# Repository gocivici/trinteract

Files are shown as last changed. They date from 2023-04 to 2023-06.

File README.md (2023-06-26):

# Trinteract





This repository contains all the files and documentation for Trinteract, An open-source Arduino-compatible 3DOF Human Interface Device (HID). In other words a joystick that's capable of moving in all 3 Dimensions. Trinteract uses a 3D magnetometer and a Neodymium magnet to detect motion in 3D space.  [Visit the DIY guide](https://www.instructables.com/Trinteract-an-Open-source-3D-Input-Device/)

[Watch the Demo here](https://youtu.be/YoGgdORVARs)

File structure:
+  `Software` contains the arduino code and necessary drivers 
+  `PCB` contains the KiCAD PCB files and gerber files for manufacturing
+  `docs` contains the source code for the documentation website build with [Sphinx](https://www.sphinx-doc.org/en/master/index.html)
+  `CAD` contains all fusion360 CAD files and print ready .stl files  

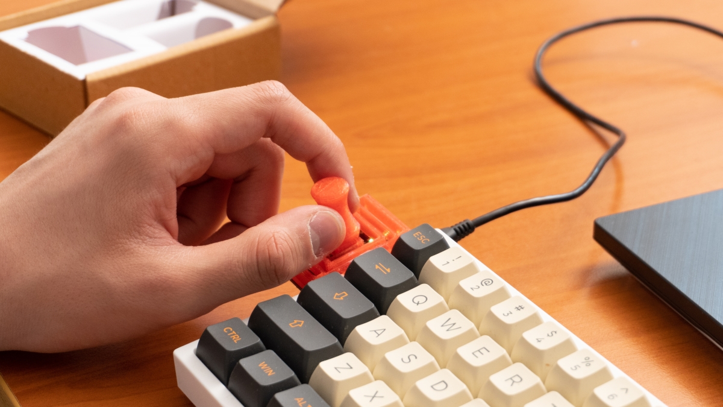
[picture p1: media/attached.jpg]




Before Assembly            |  Assembled
:-------------------------:|:-------------------------:
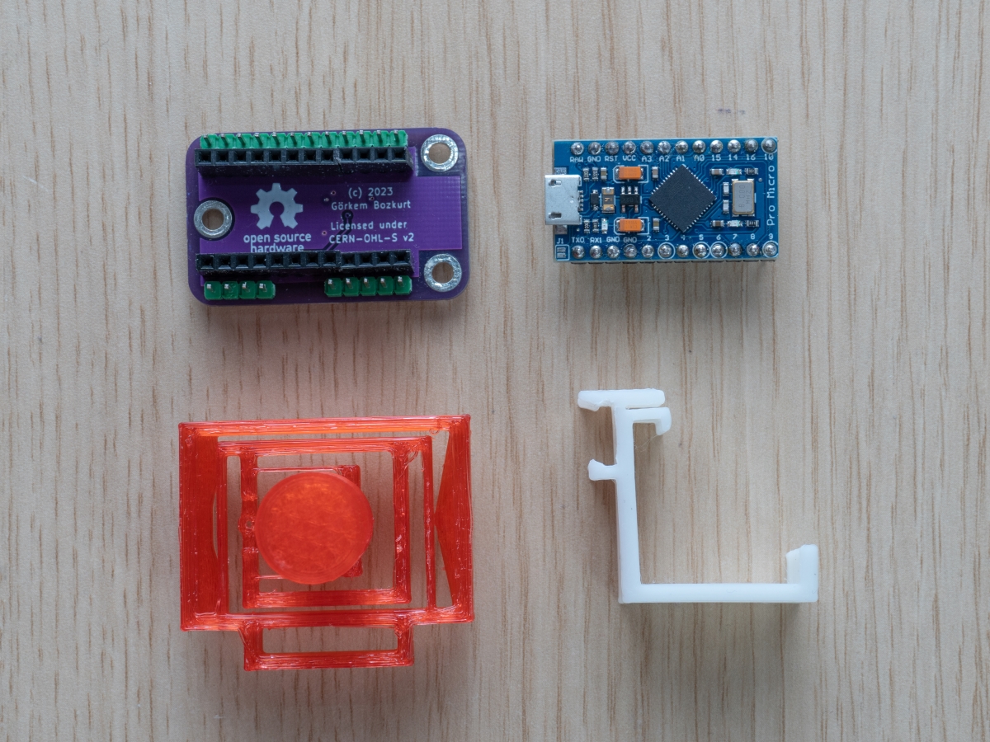
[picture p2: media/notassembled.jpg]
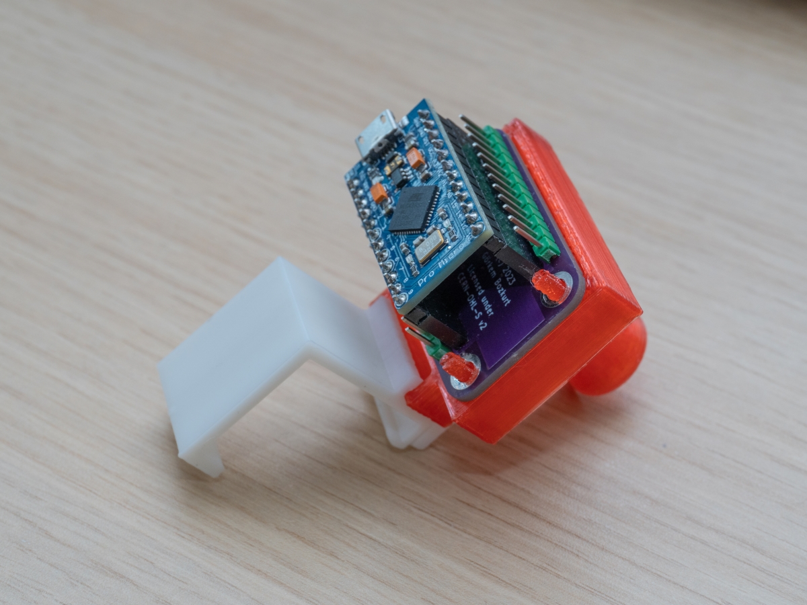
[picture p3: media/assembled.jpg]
  |  

<p align="center" width="100%">
    
</p>
<p align="center" width="100%">
<a href="https://certification.oshwa.org/ee000001.html">[OSHW] EE00001 | Certified open source hardware</a>
</p>

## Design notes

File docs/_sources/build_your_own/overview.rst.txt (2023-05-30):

Overview
========

Trinteract is basically a compact breakout board for the TLV493 Magnetometer. You can use off-the-shelf components to prototype it first before you 
order a PCB. Here's a wiring guide for a simple prototype that features the magnetic sensor, an Arduino pro micro, a LED and a tactile button: 

.. image:: wiring.png

If you decide to manufacture the PCB you can follow `this interactive BOM guide <../ibom.html>`_ to keep track of the parts: 

Parts for PCB
-------------

* :doc:`Trinteract pcb </build_your_own/Fabrication>` 
* `Infenion TLV493DA Low Power 3D Magnetic Sensor <https://eu.mouser.com/ProductDetail/Infineon-Technologies/TLV493DA1B6HTSA2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>`_
* '2 x 2.2k Ω SMD Resistor 0805 - R1 & R3
* '680 Ω SMD Resistor 0805 - R2
* '4.7k Ω SMD Resistor 0805 - R4
* '100n SMD Capacitor 0805 - C1
* 'Tactile Switch 5 X 5mm,  2 mm Actuator Height
* 4x4mm neodymium cube magnet

': *These parts can be bought from any major electronics supplier, like Digikey or Mouser*

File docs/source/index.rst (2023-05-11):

Contents
--------
.. toctree::
   :maxdepth: 2
   :caption: ✨ Getting Started

   getting_started/Quick Start
   getting_started/Installation
   getting_started/Configuration
   getting_started/Examples

.. toctree::
   :maxdepth: 2
   :caption: 🛠️ Build Your Own

   build_your_own/overview
   build_your_own/Fabrication
   build_your_own/Soldering
   build_your_own/3D Printing
   build_your_own/Testing
.. toctree::
   :maxdepth: 2
   :caption: 📖 Development

   development/About
   development/Contributing
   development/Changelog

Indices and tables
==================

* :ref:`genindex`
* :ref:`modindex`
* :ref:`search`

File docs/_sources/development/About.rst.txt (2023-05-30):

About
=====

About Trinteract
----------------

Trinteract was developed as part of an Interaction design Masters thesis project in May 2023, the starting point for the project was the challanges of navigating 3D environments and 
the absence of universal  3D  input  devices for the average user. 

It combines the advantages of the mouse and existing commercial devices like the SpaceMouse to provide an easy-to-learn customizable 3DOF navigation experience.

About this documentation
------------------------

This documentation was build in parallel with the development of trinteract and aims to encougrage user involvement through the development process. 

If you want to contribute to Trinteract or this document, please see: :doc:`Contributing <Contributing>`

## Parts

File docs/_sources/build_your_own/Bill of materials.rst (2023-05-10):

Bill of materials(BOM)
======================

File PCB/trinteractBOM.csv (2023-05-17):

Id | Designator | Package | Quantity | Designation | Supplier and ref
1 | D1 | 156120GS82500 | 1 | LED
2 | R3,R1 | R_0805_2012Metric_Pad1.20x1.40mm_HandSolder | 2 | 2k2
3 | R2 | R_0805_2012Metric_Pad1.20x1.40mm_HandSolder | 1 | 680R
4 | U1 | TLV493DA1B6HTSA2 | 1 | TLV493DA1B6HTSA2
5 | C1 | C_0805_2012Metric_Pad1.18x1.45mm_HandSolder | 1 | 100n
6 | U2 | ARDUINO_PRO_MICRO | 1 | ProMicro
7 | SW1 | SW_SPST_TL3342 | 1 | SW_Push
8 | J3 | Female_Header_1x12-Pin_P2.54mm_Horizontal | 2 | 1x12
9 | R4 | R_0805_2012Metric_Pad1.20x1.40mm_HandSolder | 1 | 4k7

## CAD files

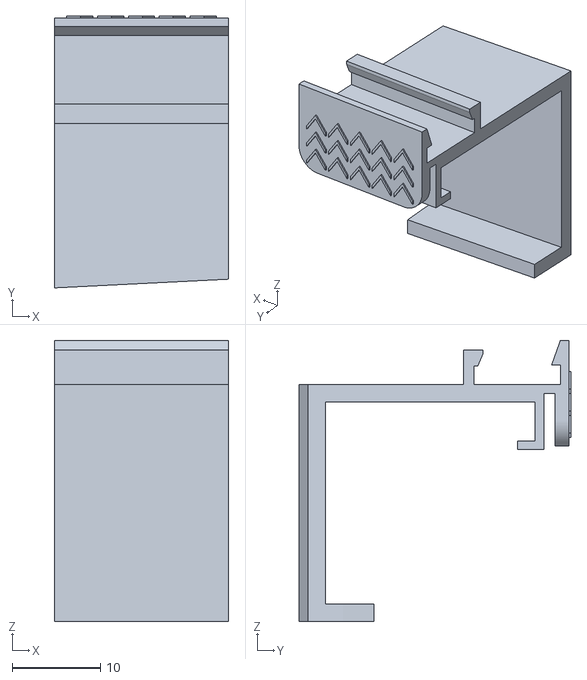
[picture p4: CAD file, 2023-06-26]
CAD/stl/KeyboardAdapter.stl
19.8 x 30.8 x 31.9

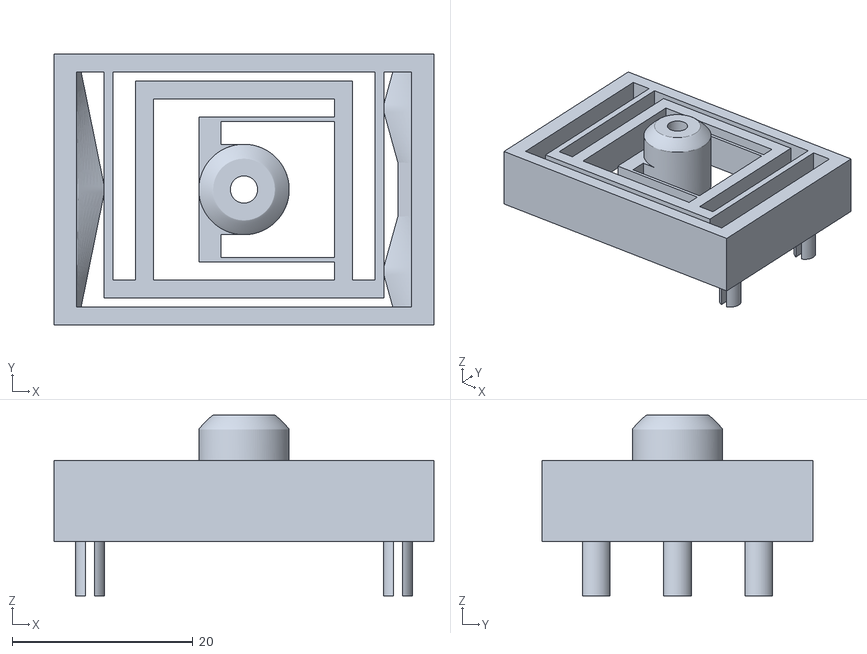
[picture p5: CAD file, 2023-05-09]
CAD/stl/base.stl
42.0 x 30.0 x 20.0

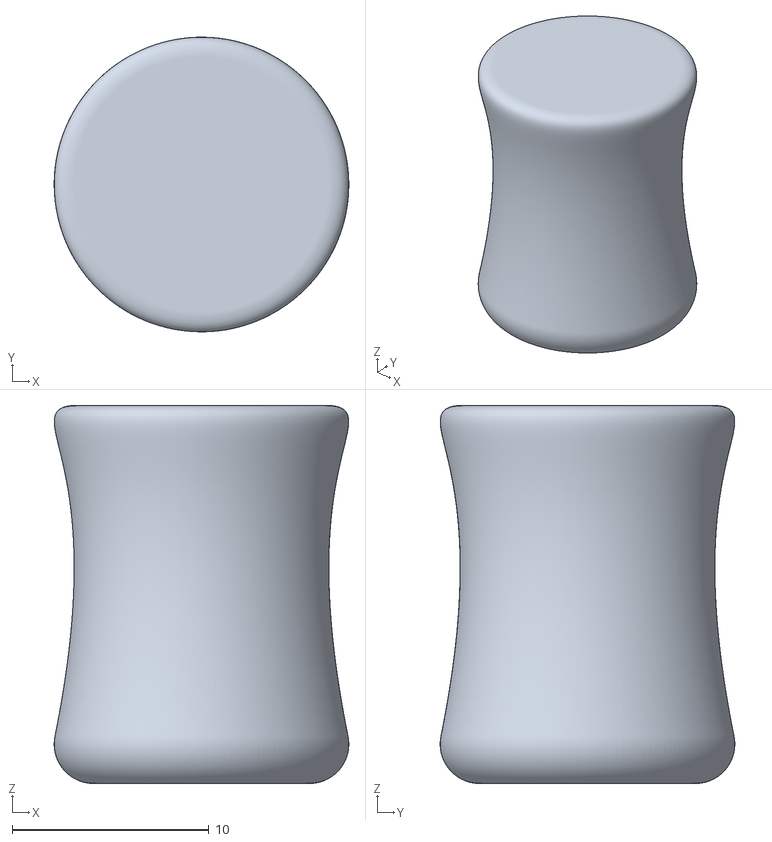
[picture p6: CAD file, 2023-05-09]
CAD/stl/knob.stl
15.0 x 15.0 x 19.2

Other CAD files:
CAD/KeyboardAdapter.f3z
CAD/base.f3d
CAD/knob.f3d

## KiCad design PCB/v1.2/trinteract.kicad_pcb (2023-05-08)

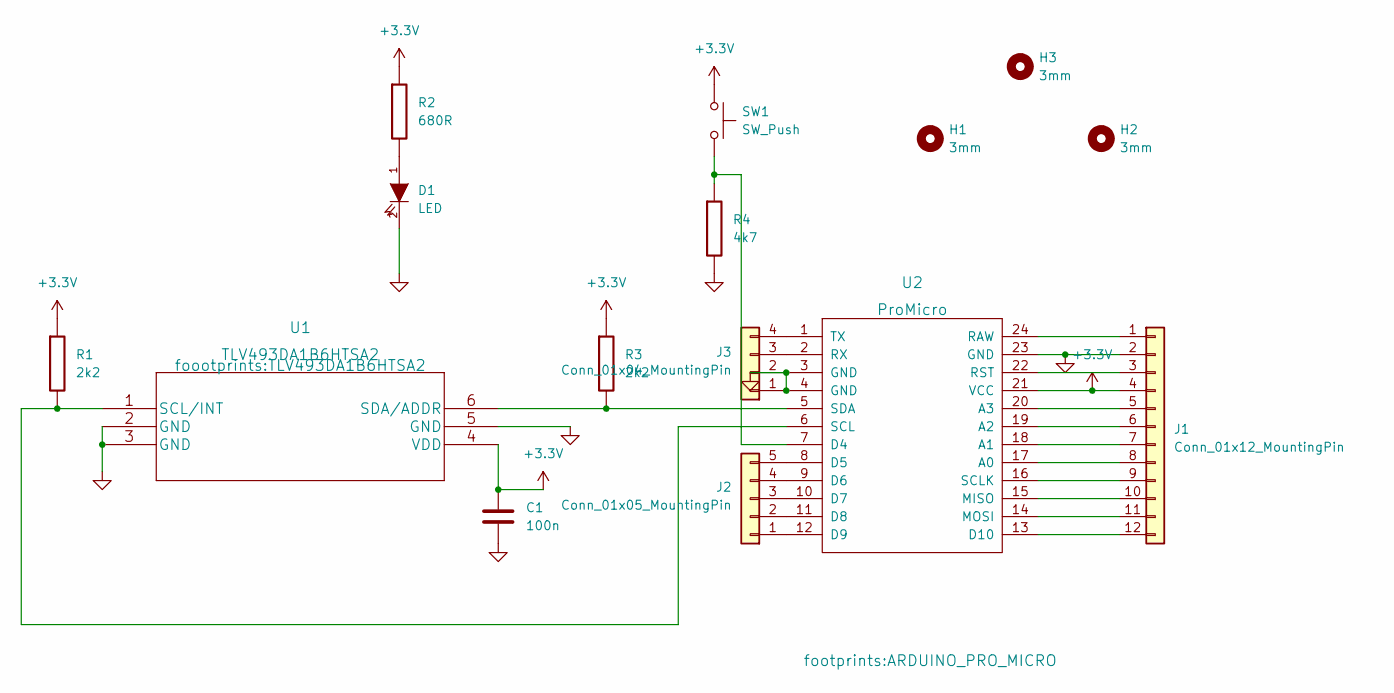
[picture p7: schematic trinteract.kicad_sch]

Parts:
C1: 100n; C_0805_2012Metric_Pad1.18x1.45mm_HandSolder
D1: LED; 156120GS82500
H1, H2, H3: 3mm; MountingHole_3.2mm_M3_DIN965_Pad
J1: Conn_01x12_MountingPin; PinHeader_1x12_P2.54mm_Horizontal
J2: Conn_01x05_MountingPin; PinHeader_1x05_P2.54mm_Horizontal
J3: Conn_01x04_MountingPin; PinHeader_1x04_P2.54mm_Horizontal
R1, R3: 2k2; R_0805_2012Metric_Pad1.20x1.40mm_HandSolder
R2: 680R; R_0805_2012Metric_Pad1.20x1.40mm_HandSolder
R4: 4k7; R_0805_2012Metric_Pad1.20x1.40mm_HandSolder
SW1: SW_Push; SW_SPST_TL3342
U1: TLV493DA1B6HTSA2
U2: ProMicro; ARDUINO_PRO_MICRO

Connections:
+3.3V: C1.1, J1.4, R1.1, R2.1, R3.1, SW1.1, U1.4 (VDD), U2.21 (VCC)
GND: C1.2, D1.2 (K), J1.2, J3.1, J3.2, R4.2, U1.2 (GND), U1.3 (GND), U1.5 (GND), U2.3 (GND), U2.4 (GND), U2.23 (GND)
unnamed: D1.1 (A), R2.2
unnamed: R1.2, U1.1 (SCL/INT), U2.6 (SCL)
unnamed: R3.2, U1.6 (SDA/ADDR), U2.5 (SDA)
unnamed: R4.1, SW1.2, U2.7 (D4)
unnamed: J3.4, U2.1 (TX)
unnamed: J3.3, U2.2 (RX)
unnamed: J2.5, U2.8 (D5)
unnamed: J2.4, U2.9 (D6)
unnamed: J2.3, U2.10 (D7)
unnamed: J2.2, U2.11 (D8)
unnamed: J2.1, U2.12 (D9)
unnamed: J1.12, U2.13 (D10)
unnamed: J1.11, U2.14 (MOSI)
unnamed: J1.10, U2.15 (MISO)
unnamed: J1.9, U2.16 (SCLK)
unnamed: J1.8, U2.17 (A0)
unnamed: J1.7, U2.18 (A1)
unnamed: J1.6, U2.19 (A2)
unnamed: J1.5, U2.20 (A3)
unnamed: J1.3, U2.22 (RST)
unnamed: J1.1, U2.24 (RAW)

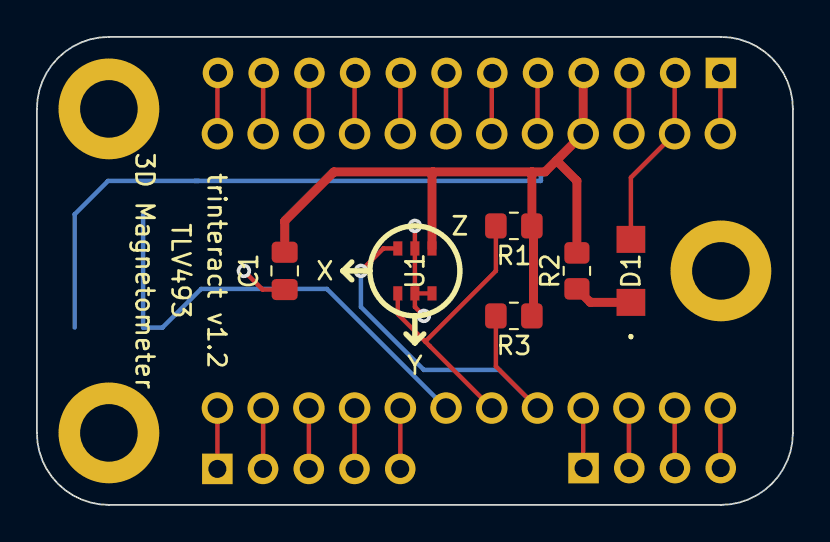
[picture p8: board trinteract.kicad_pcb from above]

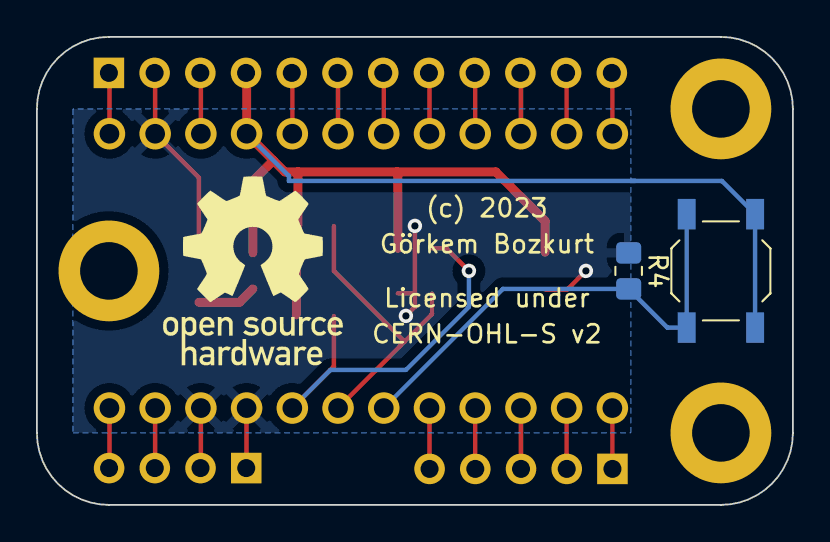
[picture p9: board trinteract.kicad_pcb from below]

Board: 2 copper layers, 42.0 x 26.0 mm, 15 parts (5 on the bottom side), 23 nets.

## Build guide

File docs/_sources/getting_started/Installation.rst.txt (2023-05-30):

Interactive Tutorial
====================
This interactive guide will guide you through the capabilities of the sensor. But first you have to use a plugin to let figma communicate with trinteract.

Launch Figma and go to ``Plugins`` and search for "3DConnexion SpaceMouse Driver" by Chuanqi Sun

Attach Trinteract to your computer and you are ready to navigate Figma! 

.. raw:: html

    <iframe style="border: 1px solid rgba(0, 0, 0, 0.1);" width="800" height="450" src="https://www.figma.com/embed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" allowfullscreen></iframe>

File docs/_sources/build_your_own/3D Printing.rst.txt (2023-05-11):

3D Printing
===========

.. image:: cura.png
    :width: 80%
    :align: center

The latest CAD files can downloaded from `this link. <https://github.com/gocivici/trinteract/archive/refs/heads/master.zip>`_ The CAD files can be edited in Fusion360. You can also use the .stl files directly for the 3D printing.

The 3D prints were done on a fdm printer with a eSun PLA+ filament. The following settings were used for the print:

* Layer Height: 0.25mm
* Wall thickness: 1.2mm
* infill: 50%
* Generate support, Overhang Angle:60

.. image:: 3D.jpg
    :width: 45%

.. image:: 3D2.jpg
    :width: 45%

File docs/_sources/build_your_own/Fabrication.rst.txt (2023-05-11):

PCB Fabrication
===============

Schematic and PCB
-----------------

.. image:: pcb.png

The latest PCB files can downloaded from `this link <https://github.com/gocivici/trinteract/archive/refs/heads/master.zip>`_

There are two subfolders under the PCB folder. One contains the KiCAD files that can be edited and customized. The other folder titled "Gerbers" contains the manufacture ready files 
that can be directly sent to a PCB manufacturer like JLCPCB.

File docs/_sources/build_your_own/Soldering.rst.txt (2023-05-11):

Soldering
=========

SMD Components
--------------

.. image:: solder.jpg
    :width: 45%

.. image:: solder2.jpg
    :width: 45%

.. note::
   The PCB in these pictures are from the previous version, I'll update them once I receive the new batch. The only difference in the new version is the button placement. The newer version has the button on the back.

The components can be soldered on to the PCB by hand, but you could also use solder paste and a reflow oven to make the process easier. I followed this tutorial 
for the hand soldering:

.. raw:: html
    
    <iframe width="560" height="315" src="https://www.youtube.com/embed/4zXP0TtORWo" title="YouTube video player" frameborder="0" allow="accelerometer; autoplay; clipboard-write; encrypted-media; gyroscope; picture-in-picture; web-share" allowfullscreen></iframe>

Through-Hole Components
-----------------------

The only Through-Hole components in this build are te header pins. You can also solder additional expansion pins if you plan to prototype with the board.

.. image:: hole.jpg
    :width: 60%
    :align: center

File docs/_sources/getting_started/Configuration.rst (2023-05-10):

Configuration
=============

The Arduino code for trinteract can be found in the Software folder in the github repository. You can download the latest version by clicking the following link: https://github.com/gocivici/trinteract/archive/refs/heads/master.zip

Different Magnet
----------------

the Arduino code comes configured and calibrated based on a 4x4mm neodymium magnet. If you want to use a different magnet or magnetic material like magnetic textiles etc. you have to
configure the range of the magnetic field in the Arduino code.

First uncomment the following lines to open the serial port:

.. code-block:: c++

  //  uncomment the following line for debugging
  Serial.begin(9600);

.. code-block:: c++

  Serial.print(Tlv493dMagnetic3DSensor.getX());
  Serial.print(Tlv493dMagnetic3DSensor.getY());
  Serial.println(Tlv493dMagnetic3DSensor.getZ());

Next, upload the code to arduino and launch the serial monitor to see the new values. Now move the magnet to the maximum and minimum ends to determine the range of values.

Replace ``xMin``, ``xMax``, ``yMin``, ``yMax``, ``zMin``, ``zMax`` with the new values.

.. code-block:: c++

  int y = map((calX-Tlv493dMagnetic3DSensor.getX()),yMax,yMin,-64,64);
  int x = map((calY-Tlv493dMagnetic3DSensor.getY()),xMax,xMin,-64,64);
  int z = map((calZ-Tlv493dMagnetic3DSensor.getZ()),zMin,zMax,-64,64);

The Button
----------

The button on trinteract is set up as a calibration button, however calibration is also implemented on boot so you can configure to use it to control something else. If you decide to do so you can 
comment the following line in the arduino code:

.. code-block:: c++

    // comment the following lines if you want to use the button for something else
    if(digitalRead(calButton) || !calibrationState){
      calibrate();
      calibrationState = true;
    }

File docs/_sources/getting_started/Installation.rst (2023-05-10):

Interactive Tutorial
====================
This interactive guide will guide you throug the capabilities of the sensor. But first you have to use a plugin to let figma communicate with trinteract.
download the zxyKit driver from here, unzip the folder and on Figma goto Plugins → Development → trinteract Driver.

.. raw:: html

    <iframe style="border: 1px solid rgba(0, 0, 0, 0.1);" width="800" height="450" src="https://www.figma.com/embed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" allowfullscreen></iframe>

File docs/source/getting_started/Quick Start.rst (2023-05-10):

Quick Start
===========

To get started with **trinteract**, connect an **3.3v** arduino pro micro to the board as shown in the picture along with the 3D printed top. If you're building your own kit head over to the :doc:`🛠️ Build Your Own </build_your_own/overview>` section.

.. admonition:: Important
   :class: attention

   trinteract is only compatible with 3.3 volts, any higher voltage could fry the sensor

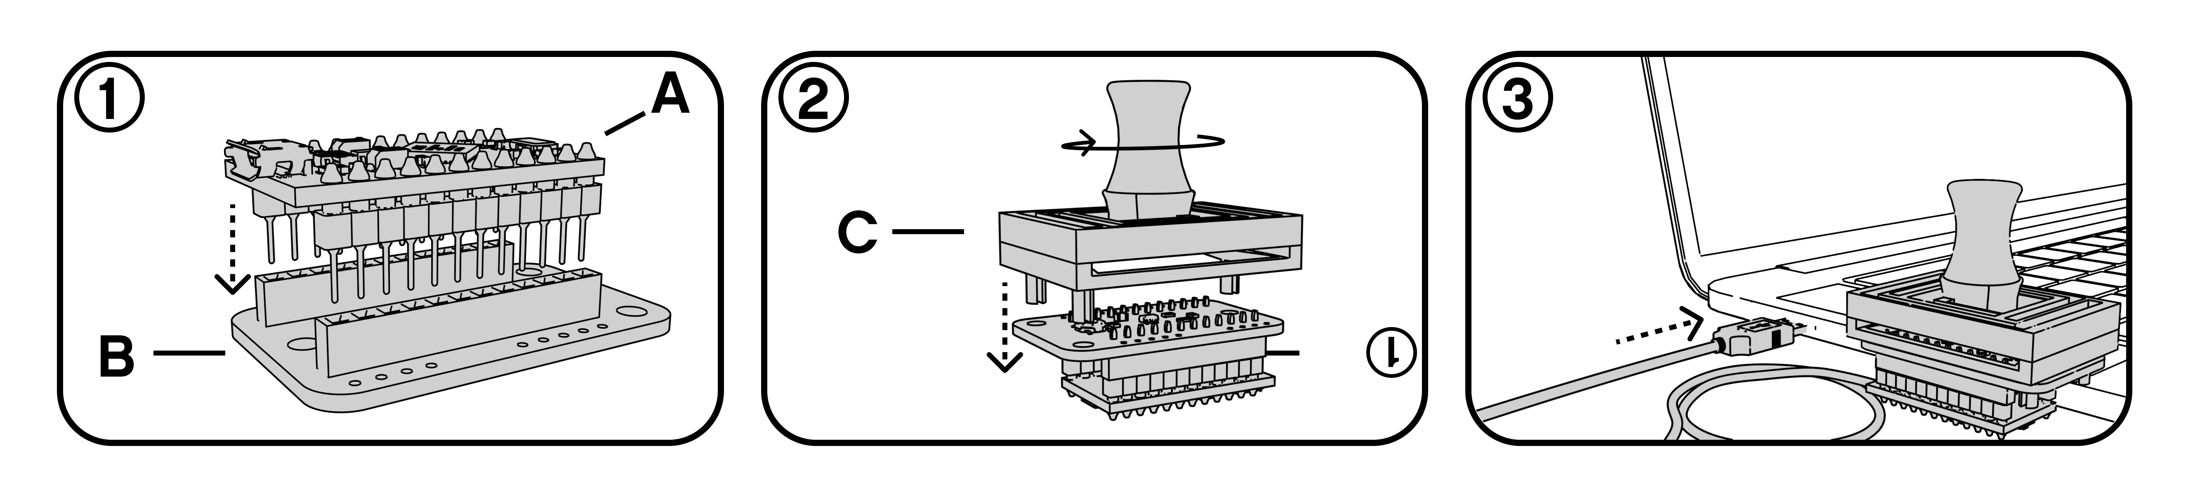
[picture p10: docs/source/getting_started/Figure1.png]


..  It can track movement in all 3 axes, and you can customize it further by following the
.. instructions on this website.

 .. note::
..    The zxyKit is pre-configured to work with **Blender** out of the box, If you want to use it with other software
..    visit the :doc:`Configuration` page.

.. :abbr:`HTML (Hyper Text Markup Language)`

.. Next, launch the interactive tutorial on figma following the link below.

.. - To get started:

..   - Attach the purple board to the Arduino as shown in the picture.
..   - Connect the board to your computer using the micro usb cable.
..   - Launch Blender and go into fly mode from the ``View ‣ Navigation`` menu. 
..     Or using the ``Shift`` + ``accent grave`` shortcut. 

On Windows, Your computer will recognize trinteract as a game controller. To check if it's recognized go to:
``Control Panel`` → ``Devices and Printers`` → ``Set up USB game controllers`` and click ``Properties``

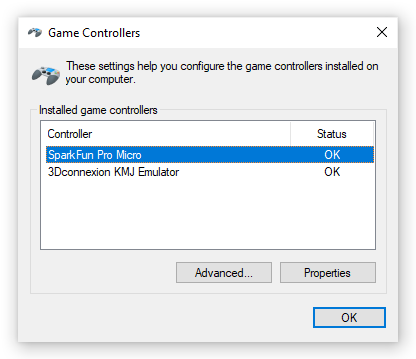
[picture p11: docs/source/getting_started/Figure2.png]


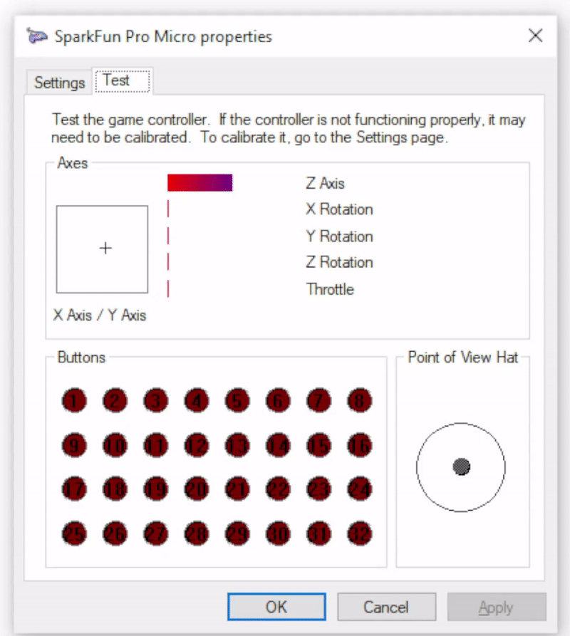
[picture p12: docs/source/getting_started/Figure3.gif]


.. note::
   If trinteract isn't recognized on your computer you can visit the Troubleshooting guide here

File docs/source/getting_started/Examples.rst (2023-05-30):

Examples
========

Blender
-------

Keyboard Bindings
-----------------

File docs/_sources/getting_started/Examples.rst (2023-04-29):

Examples
========

Installation
------------

I'm testing thissss

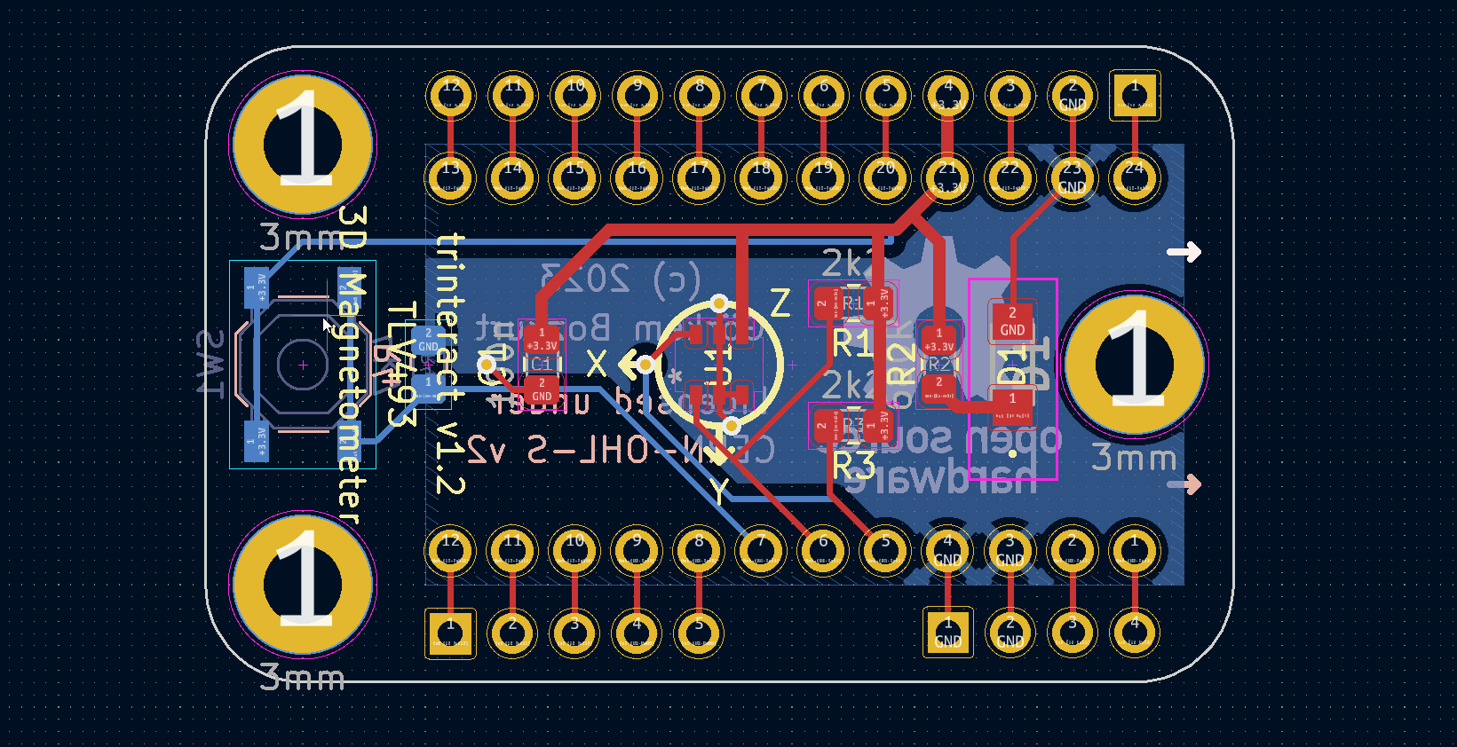
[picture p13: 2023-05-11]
docs/source/build_your_own/pcb.png

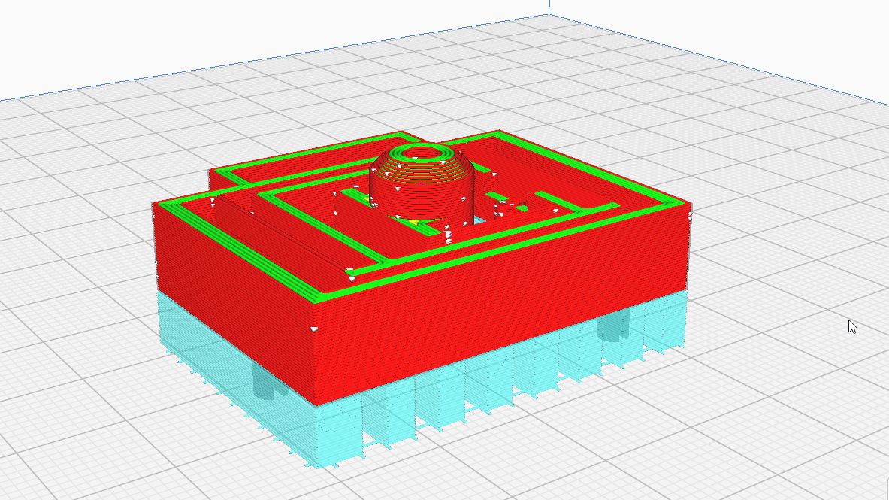
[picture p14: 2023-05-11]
docs/source/build_your_own/cura.png

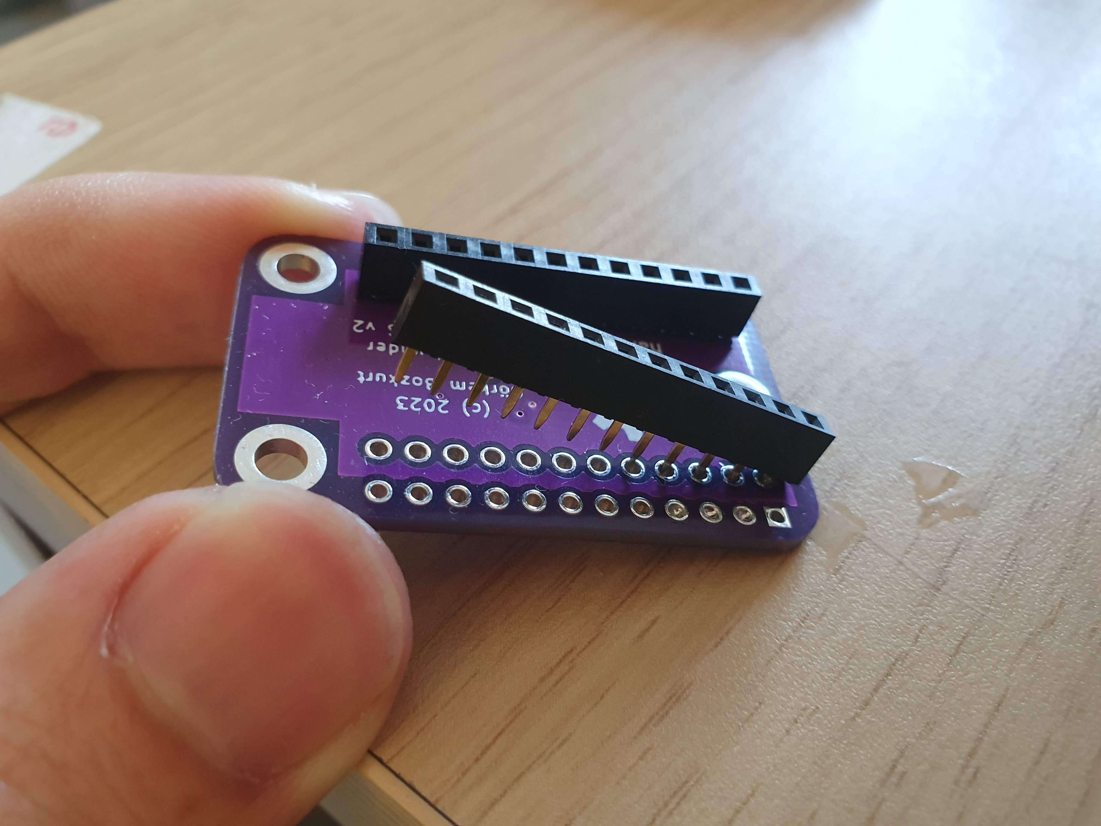
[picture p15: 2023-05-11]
docs/source/build_your_own/hole.jpg

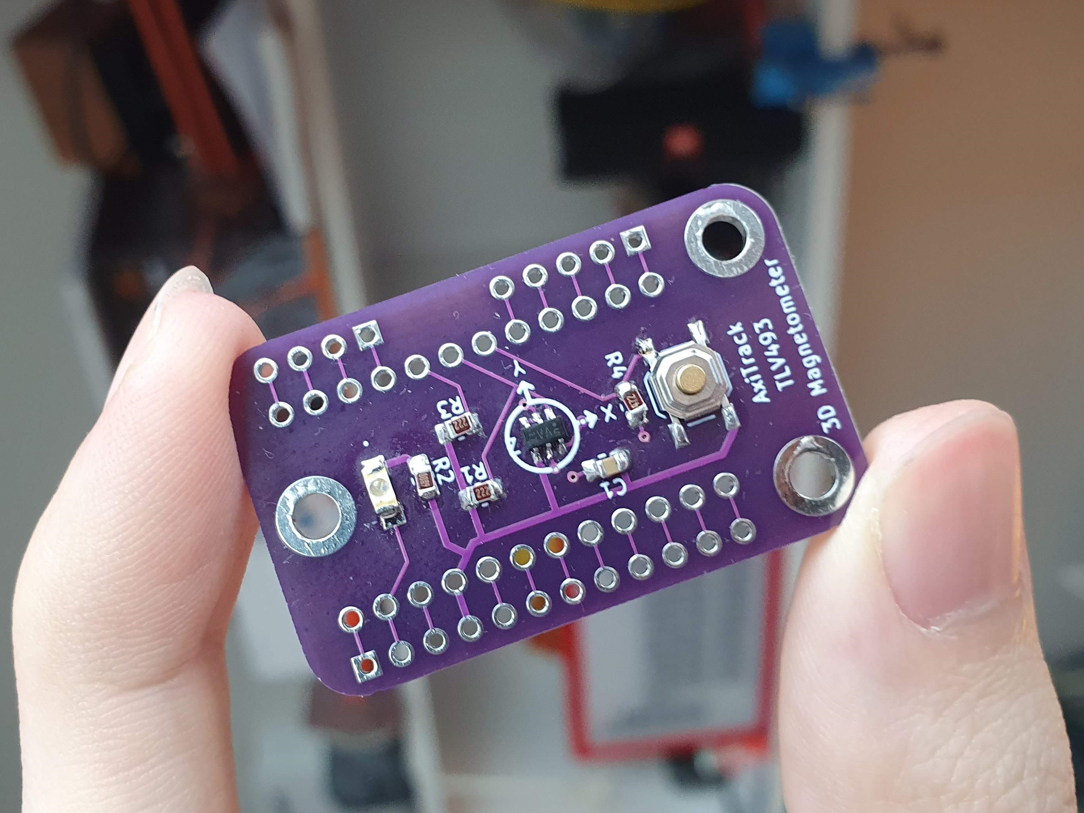
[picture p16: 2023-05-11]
docs/source/build_your_own/solder2.jpg

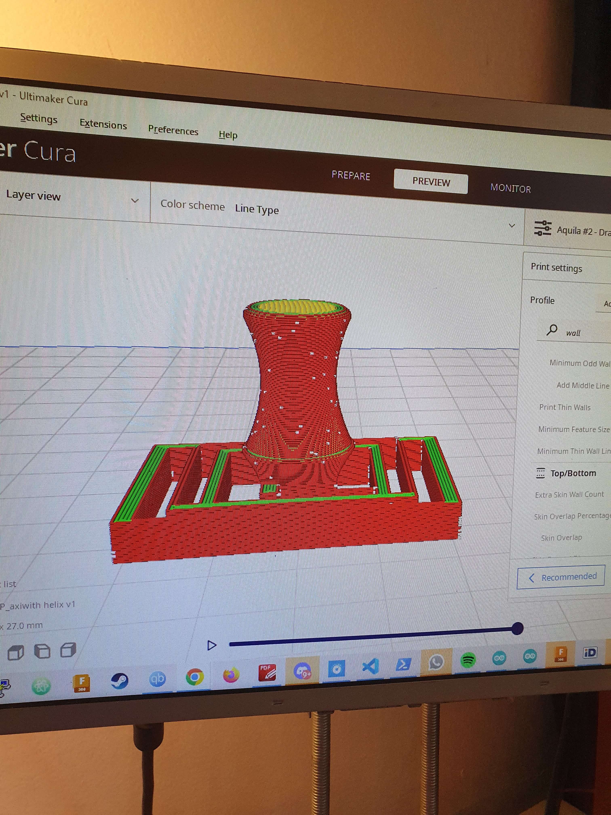
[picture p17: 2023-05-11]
docs/source/build_your_own/20230416_154522.jpg

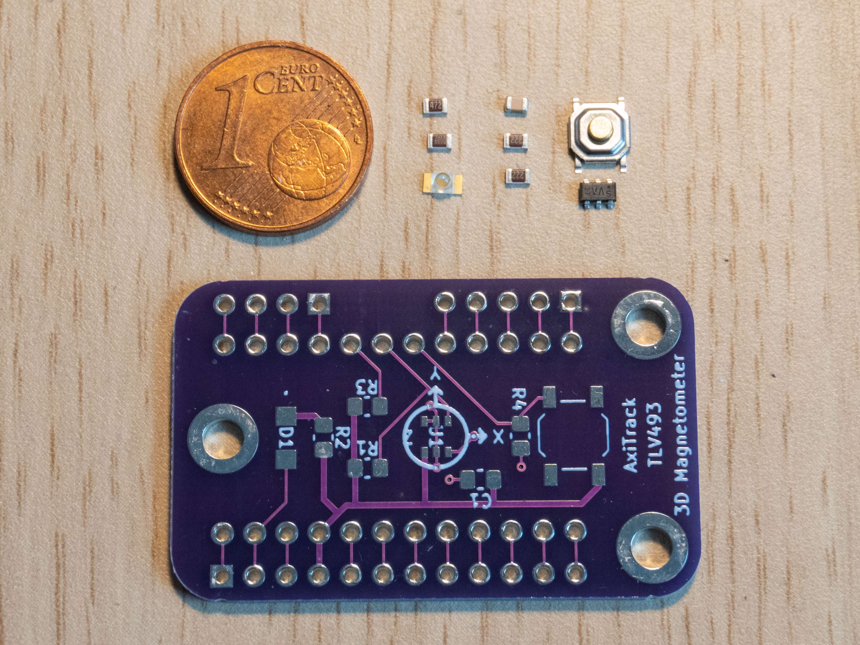
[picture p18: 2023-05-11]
docs/source/build_your_own/solder.jpg

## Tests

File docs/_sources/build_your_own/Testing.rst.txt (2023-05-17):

Assembly and Testing
====================

Connecting to Arduino
---------------------

.. image:: ardu.jpg
    :width: 45%

.. image:: ardu2.jpg
    :width: 45%

After you conect the board to arduino as shown in the picture, download the arduino code from  `the repository <https://github.com/gocivici/trinteract>`_ and upload the code to the
arduino with the following settings:

.. image:: ide.png
    :width: 60%
    :align: center

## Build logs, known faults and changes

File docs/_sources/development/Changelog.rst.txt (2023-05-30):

Changelog
=========

.. changelog::
   :towncrier:

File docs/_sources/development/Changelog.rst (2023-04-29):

hangelog
========

Installation
------------

I'm testing thissss

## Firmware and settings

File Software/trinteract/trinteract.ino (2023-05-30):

#include <Joystick.h>
#include <Tlv493d.h>

Tlv493d Tlv493dMagnetic3DSensor = Tlv493d();
Joystick_ Joystick;

//defined values for calibration
float calX = 0;
float calY = 0;
float calZ = 0;
boolean calibrationState = false;
int calButton = 4;

void setup() {
//  uncomment the following line for debugging
//  Serial.begin(9600);
  pinMode(calButton, INPUT);
  
  Tlv493dMagnetic3DSensor.begin();
  Tlv493dMagnetic3DSensor.setAccessMode(Tlv493dMagnetic3DSensor.MASTERCONTROLLEDMODE);
  Tlv493dMagnetic3DSensor.disableTemp();
  
// set joystick axis range
  Joystick.setXAxisRange(-512, 512);
  Joystick.setYAxisRange(-512, 512);
  Joystick.setZAxisRange(-512, 512);

}

void loop() {
  // delay for measurment
  delay(Tlv493dMagnetic3DSensor.getMeasurementDelay());
  Tlv493dMagnetic3DSensor.updateData();

    // do calibration when button pressed
    if(digitalRead(calButton) || !calibrationState){
    calibrate();
    calibrationState = true;
    }

// map values from the sensor to joystick axis range
int y = map((calX-Tlv493dMagnetic3DSensor.getX()),32,-32,-512,512);
int x = map((calY-Tlv493dMagnetic3DSensor.getY()),32,-32,-512,512);
int z = map((calZ-Tlv493dMagnetic3DSensor.getZ()),-30,30,-512,512);

//    Serial.print(Tlv493dMagnetic3DSensor.getX());
//    Serial.print(Tlv493dMagnetic3DSensor.getY());
//    Serial.println(Tlv493dMagnetic3DSensor.getZ());

  Joystick.setXAxis(x);
  Joystick.setYAxis(y);
  Joystick.setZAxis(z);
//
//  if(z>10){
//  Joystick.setZAxis(z-10);
//  }
//  else if(z<-20){
//  Joystick.setZAxis(z+20);
//  } else {
//    Joystick.setZAxis(0);
//    }
  

  Joystick.sendState();

}

void calibrate(){
    calX = Tlv493dMagnetic3DSensor.getX();
    calY = Tlv493dMagnetic3DSensor.getY();
    calZ = Tlv493dMagnetic3DSensor.getZ();
//    Serial.print(calX);
//    Serial.print(calY);
//    Serial.println(calZ);
  }

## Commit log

2023-04-29 changed directory
    [Configuration.rst.txt]
2023-05-08 added gerber files for manufacturing
    [trinteract-B_Cu.gbl, trinteract-B_Mask.gbs, trinteract-B_Paste.gbp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]
2023-05-08 updated arduino code
    [trinteract.kicad_pcb]
2023-05-08 updating docs
    [Configuration.rst.txt]
2023-05-09 remove fullscreen button
    [Configuration.rst.txt]
2023-05-09 added stl files
    [base.f3d, base.stl, knob.f3d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]
2023-05-10 added new doc pages
    [Configuration.rst.txt]
2023-05-17 added BOM
    [trinteractBOM.csv]
2023-06-26 edited wiki and added 3D files
    [KeyboardAdapter.f3z, KeyboardAdapter.stl]

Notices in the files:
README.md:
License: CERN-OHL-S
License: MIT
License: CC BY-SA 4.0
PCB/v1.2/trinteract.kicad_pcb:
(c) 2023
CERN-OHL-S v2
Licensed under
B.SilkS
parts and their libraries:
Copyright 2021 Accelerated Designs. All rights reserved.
